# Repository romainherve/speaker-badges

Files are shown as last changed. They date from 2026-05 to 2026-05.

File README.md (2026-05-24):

# Speaker Badge Enclosure

A 3D-printable, two-piece enclosure for an electronic event **speaker badge**,
modeled parametrically in Python with [build123d](https://github.com/gumyr/build123d).

Portrait shell, **54 × 105 × 14.5 mm**, with a gentle round bulge so the screen
nearly fills the width. A webbing strap threads through a slot on the top face and
loops around a drop-in wrap bar.

## Bill of materials
- AMOLED 1.73" round touch display (Ø48.4 glass) + CO5300 adapter board
- ESP32-S3 N16R8 devkit (28.2 × 64.4 × 4.8 mm)
- LiPo 503040 (40 × 30 × 5 mm, 600 mAh)
- TP4056 + 5 V boost, USB-C charge board
- micro SD module + 2 tactile side buttons
- **Closure:** 4× M2 countersunk screws into 4× M2 brass heat-set inserts
- **Strap bar:** printed `wrap_bar` *or* a Ø3 mm steel rod cut to ~29.4 mm

## Files
| File | Purpose |
|---|---|
| `speaker_badge.py` | the enclosure — front + back shells |
| `m2_screw.py`, `insert.py` | M2 countersunk screw + heat-set insert models |
| `wrap_bar.py` | drop-in strap wrap bar |
| `screw_assembly.py` | assembled enclosure (shells + screws + inserts + bar) |
| `exploded_view.py` | exploded view of all parts |
| `section_view.py` | cross-section through a corner screw |
| `interference.py`, `footprint_check.py` | verification scripts |

`*.step` are the generated CAD outputs (regenerable from the scripts).

## Regenerate
```sh
python3 -m venv .venv
.venv/bin/pip install build123d
.venv/bin/python speaker_badge.py   # writes speaker_badge.step
```
Each script writes its own `.step` when run directly.

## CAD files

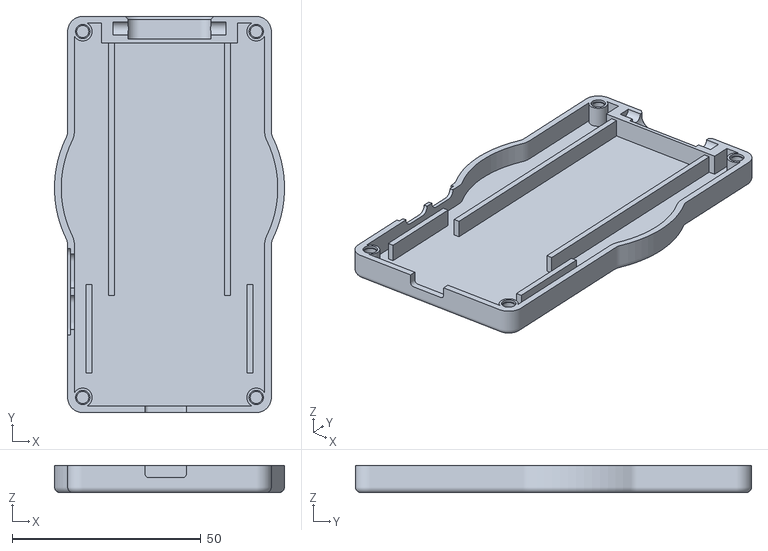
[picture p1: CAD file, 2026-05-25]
print/back_shell.stl
61.0 x 105.0 x 7.25

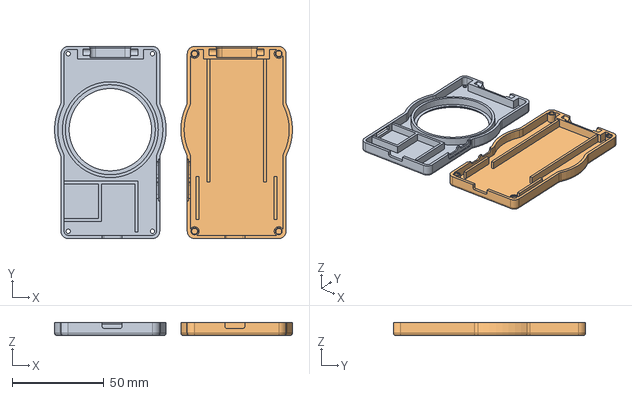
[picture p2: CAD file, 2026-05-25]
speaker_badge.step
130.0 x 105.0 x 7.25 mm

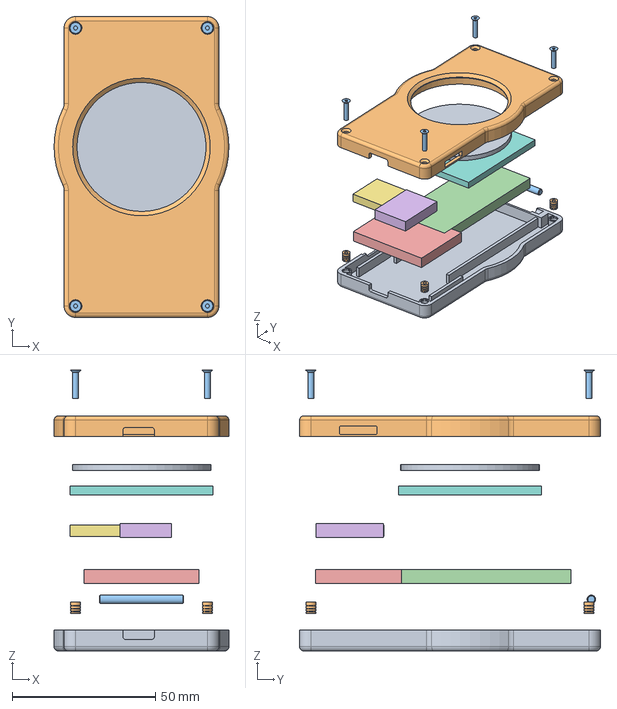
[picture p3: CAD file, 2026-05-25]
exploded_view.step
61.0 x 105.0 x 98.0 mm
screw_3 x 4

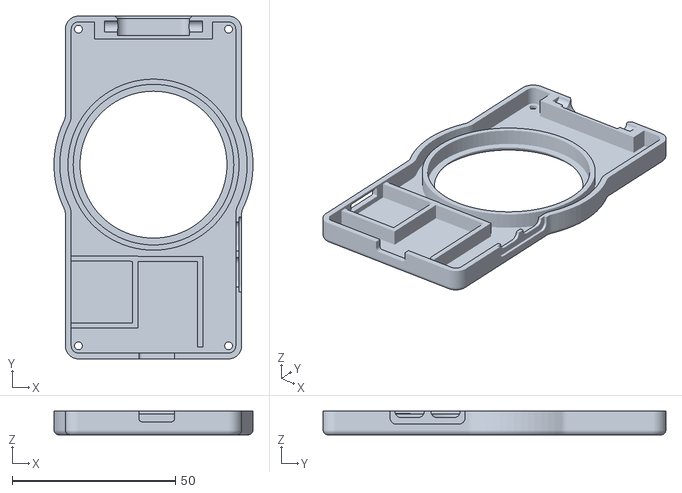
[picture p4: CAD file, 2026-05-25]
print/front_shell.stl
61.0 x 105.0 x 7.25

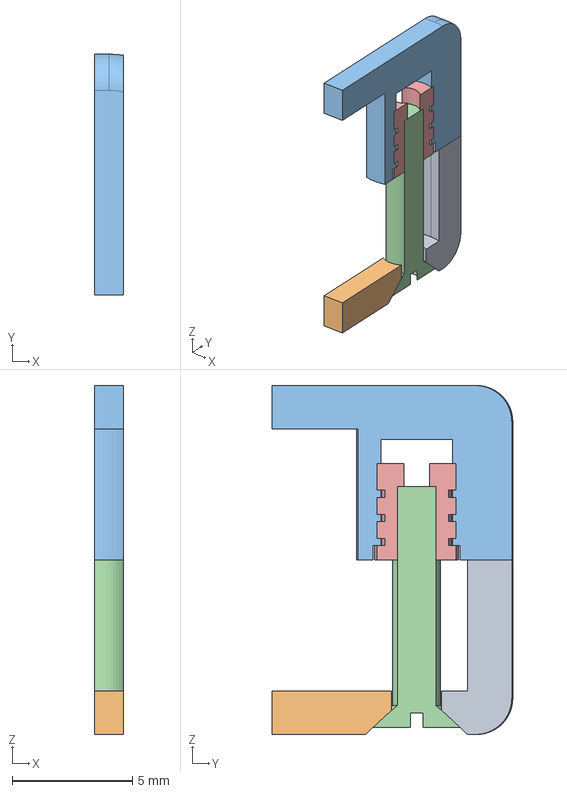
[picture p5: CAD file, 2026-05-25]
section_view.step
1.20 x 10.0 x 14.5 mm
screw_3

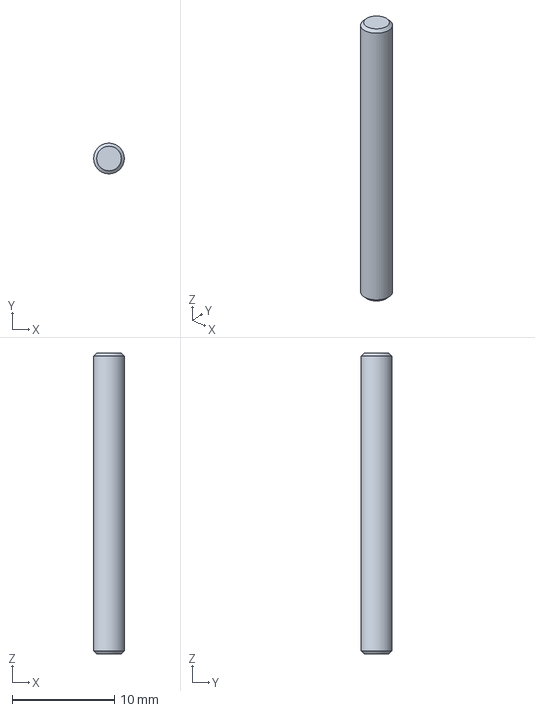
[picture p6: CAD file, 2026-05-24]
wrap_bar.step
3.00 x 3.00 x 29.4 mm

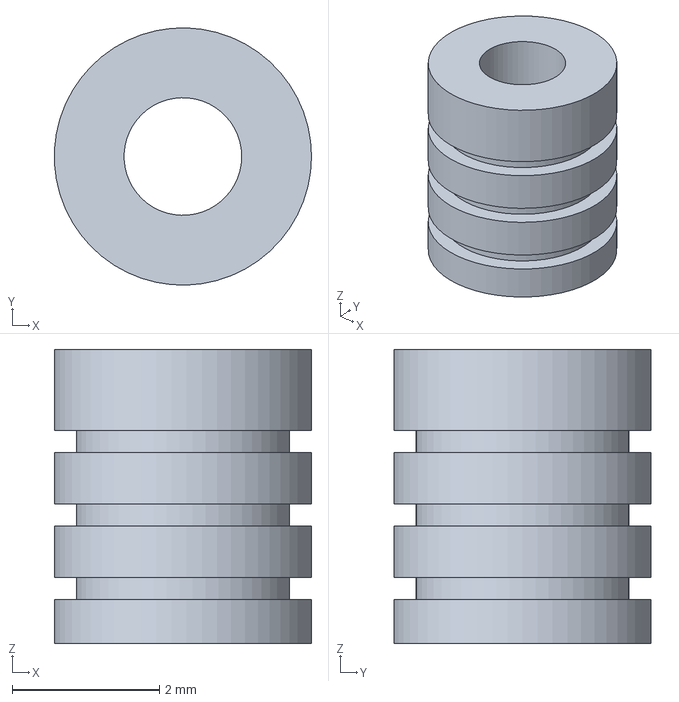
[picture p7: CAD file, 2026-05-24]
insert.step
3.50 x 3.50 x 4.00 mm

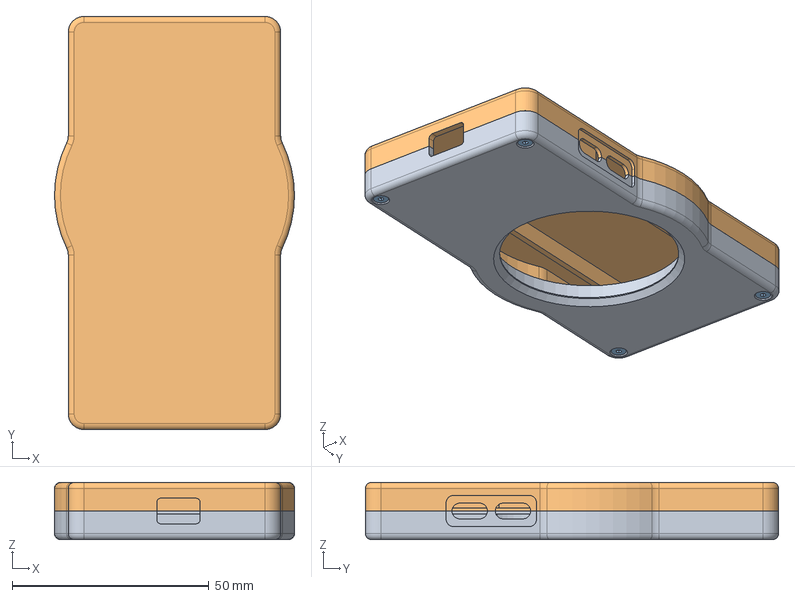
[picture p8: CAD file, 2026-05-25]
screw_assembly.step
61.0 x 105.0 x 14.5 mm
screw_3 x 4

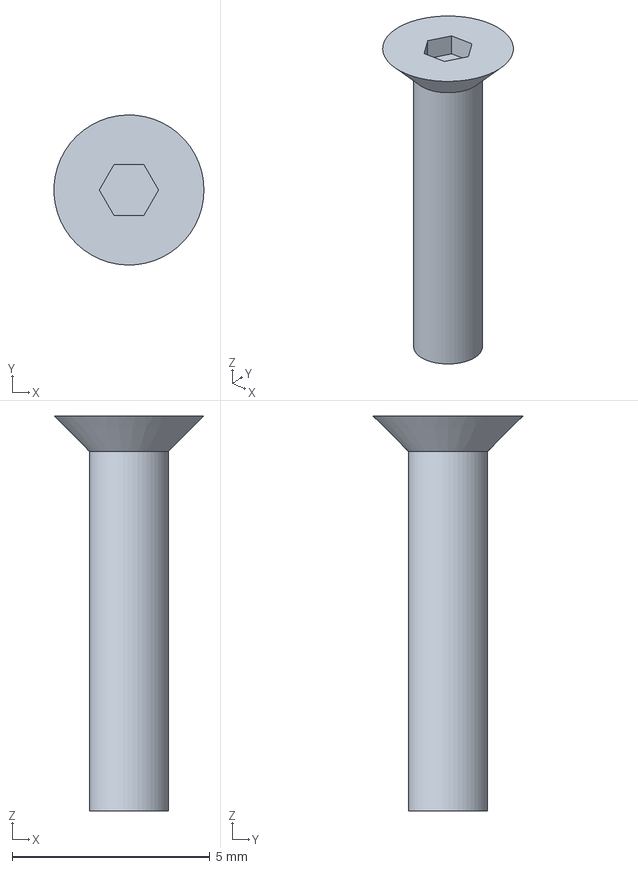
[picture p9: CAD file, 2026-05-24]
m2_screw.step
3.80 x 3.80 x 10.0 mm

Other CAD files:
print/wrap_bar.stl

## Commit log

2026-05-24 Speaker badge enclosure: parametric build123d model
    Two-piece 54x105x14.5 mm shell for an event speaker badge: round AMOLED screen,
    ESP32-S3 + LiPo stack, strap mount with drop-in wrap bar, and an M2 countersunk
    screw + heat-set insert closure. Includes assembly/exploded/section views and
    interference + footprint checks.
    [exploded_view.step, insert.step, m2_screw.step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]
2026-05-24 Stop battery ribs above the bottom insert bosses
    The battery side ribs ran full-length down past the bottom corners, crowding
    the heat-set insert bosses (and overshooting the body's bottom face). They now
    stop ~4 mm above the bosses so the inserts stand free; the bosses + perimeter
    wall still locate the battery's bottom corners. Regenerated the STEP outputs.
    [exploded_view.step, screw_assembly.step, section_view.step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]
2026-05-25 Fix edge-port alignment and make the screen bezel printable
    Two prototype-driven fixes (both touch speaker_badge.py, hence one commit):
    - Edge ports: the back shell is FLIPPED about Y to close the case (x -> -x),
    not reflected, so its USB/SD/button cuts are now mirrored in X and the
    assembled views + interference check flip it with Rotation(0,180,0) instead
    of mirror(...,XY). Ports now line up across the seam on the real prints.
    - Screen bezel: replaced the flat recess (which undercut the glass-retaining
    lip and left it floating) with a 45 deg chamfer, so the front shell prints
    face-down with no supports and the lip is backed by solid wall.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
    [exploded_view.step, screw_assembly.step, section_view.step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]
2026-05-25 Add print export: STLs for the printable parts
    print_parts.py writes print/{front_shell,back_shell,wrap_bar}.stl in the
    recommended face-down print orientation (no supports). Screws and inserts are
    bought hardware and not exported.
    [back_shell.stl, front_shell.stl, wrap_bar.stl]
2026-05-25 Widen body bulge to Ø61 for a more substantial screen side frame
    The Ø57 bulge hugged the screen too tightly, leaving thin crescents of material
    on the left/right. Bumped the screen bulge to Ø61 so the body follows a larger
    circle around the screen — side wall ~doubles (~2.3 -> ~4.3 mm to the glass
    ring). Base width stays 54 mm (the adapter is held by the flat base, not the
    bulge), so this is purely the screen surround. Regenerated STEP + STL outputs.
    [back_shell.stl, exploded_view.step, front_shell.stl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]
